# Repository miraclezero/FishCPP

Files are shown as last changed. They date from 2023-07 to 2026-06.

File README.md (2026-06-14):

# FishCPP

FishCPP is a Raspberry Pi-based system designed to conduct Conditioned Place Preference (CPP) experiments with zebrafish. The system automates camera recording, manages uniform arena illumination using NeoPixel LEDs, and uses RFID scans to initiate sessions and track device configurations.

## System Features

- **Arena Illumination**: Drives a 128-pixel WS2812B NeoPixel LED array to provide constant, uniform white light.
- **Physical Visual Cues**: Visual conditioning cues consist of physical, 3D-printed floor inserts placed within the arena: a black dots pattern and a grid pattern.
- **RFID-Initiated Sessions**: RFID scans are used to initiate the recording trials, advance experimental stages, and track system device IDs.
- **Automated Video Recording**: Controls the Raspberry Pi Camera Module to record trials (30 frames per second, 20-minute sessions) in raw `.h264` format.
- **Disk Space Verification**: Checks available disk space before starting a trial to ensure there is at least 2.5 GB of free storage.
- **Video Conversion Utility**: Includes a bash script ([convert_video.sh](file:///home/hao/Dropbox/git/FishCPP/convert_video.sh)) to convert raw `.h264` recordings to `.mp4` format using `ffmpeg`.

## Hardware Components

- Raspberry Pi (running Raspberry Pi OS)
- Raspberry Pi Camera Module
- WS2812B NeoPixel LED array (128 pixels, connected to GPIO pin 18)
- RFID Reader (operating in keyboard emulation mode)
- 3D-printed arena partition inserts (black dots versus grid pattern)

## Installation and Setup

1. Clone this repository to the Raspberry Pi:
   ```bash
   git clone https://github.com/miraclezero/FishCPP.git
   ```
2. Install the necessary Python packages:
   ```bash
   pip3 install rpi_ws281x adafruit-circuitpython-neopixel board requests
   ```
3. Enable the camera module using the Raspberry Pi configuration tool:
   ```bash
   sudo raspi-config
   ```
4. Verify that the configuration file `peerpub_config.json` exists in the `/home/pi/` directory. This file tracks the system device ID, current session ID, and experiment step.
5. Grant execute permissions to the video conversion utility:
   ```bash
   chmod +x convert_video.sh
   ```

## Experimental Workflow

1. **Initialization**: Start the main control program ([main.py](file:///home/hao/Dropbox/git/FishCPP/main.py)):
   ```bash
   python3 main.py
   ```
   The program checks for sufficient disk space (at least 2.5 GB free) and verifies that the directory is writable.
2. **Session Initiation**: Scan the appropriate RFID tag to register the subject configuration and initiate the recording script.
3. **Recording and Illumination**: The NeoPixel LED array lights up to provide constant white illumination. The system starts the camera to record a 20-minute trial, saving the video file to `/home/pi/video/`.
4. **Session Termination**: Scan the termination RFID tag to turn off the LEDs and conclude the session. The session counter in `peerpub_config.json` will automatically increment.
5. **Video Conversion**: Convert the raw video output to `.mp4` for analysis:
   ```bash
   ./convert_video.sh <filename_without_extension>
   ```

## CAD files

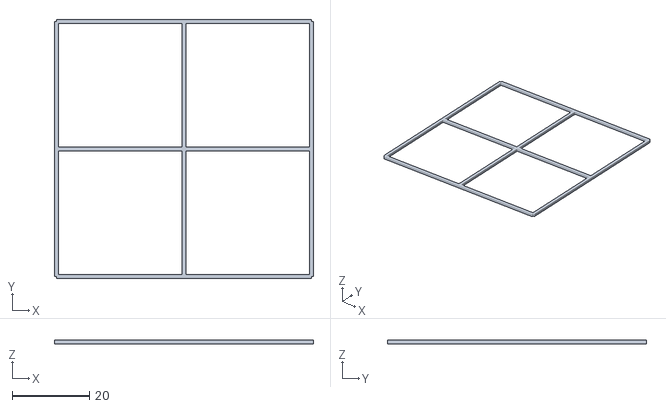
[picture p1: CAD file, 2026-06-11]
3D_design/fish_4_square_mark.stl
67.0 x 67.0 x 1.00

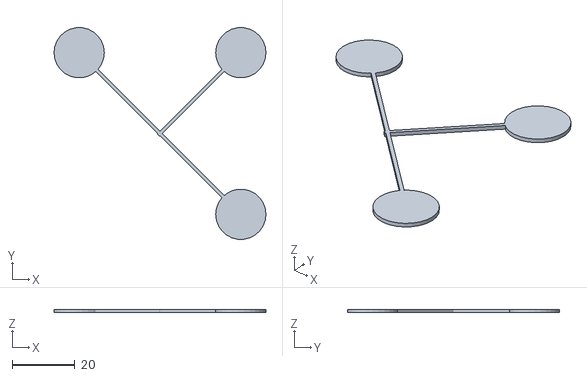
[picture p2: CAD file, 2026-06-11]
3D_design/fish_3dot_mark.stl
67.4 x 67.3 x 1.00

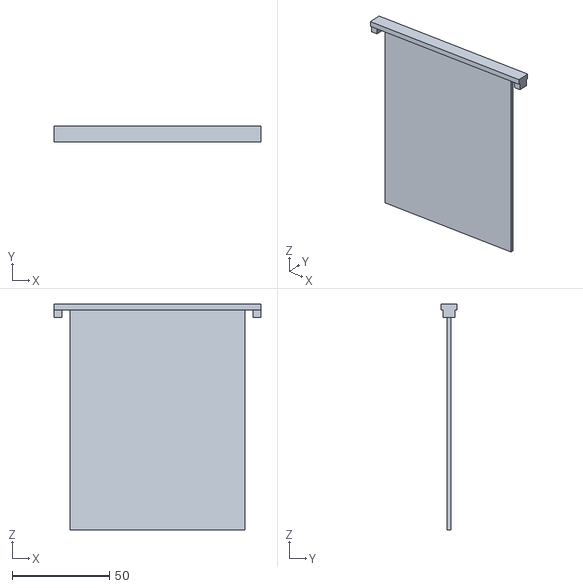
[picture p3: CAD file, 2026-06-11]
3D_design/fish_tank_mid.stl
106.0 x 8.00 x 116.0

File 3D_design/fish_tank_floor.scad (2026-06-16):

union(){
translate([15,15,0])rotate([0,0,45])cube([44, 1, 1], center=true);
translate([0,0,0])rotate([0,0,45])cube([1, 88, 1], center=true);
translate([25.7,25.7,0])rotate([0,0,0]) cylinder(r=8, h=1, center=true);
translate([-25.7,25.7,0])rotate([0,0,0]) cylinder(r=8, h=1, center=true);
translate([25.7,-25.7,0])rotate([0,0,0]) cylinder(r=8, h=1, center=true);
*translate([-25.7,-25.7,0])rotate([0,0,0]) cylinder(r=8, h=1, center=true);
}//3dot marker



union(){
    translate([0,0,0])cube([66, 1, 1], center=true);

    translate([0,33,0])cube([66, 1, 1], center=true);
    translate([0,-33,0])cube([66, 1, 1], center=true);
    translate([0,0,0])cube([1, 66, 1], center=true);

    translate([33,0,0])cube([1, 66, 1], center=true);
    translate([-33,0,0])cube([1, 66, 1], center=true);
} //grid marker

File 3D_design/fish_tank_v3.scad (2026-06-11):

$fn=50;
difference() {translate([0,0,0])cube([220+12+6, 87.5+10, 116.5+6+8+20], center=true);
 
    translate([0,-46,3+18])cube([220+5+6, 3, 116.5+8], center=true);
    translate([0,0,-50+10])cube ([220+5+8,87.5+10,4], center=true);

    translate([0,0,3]) cube ([220+6,87.5+11,116.5+8+20.1], center=true);
    translate([110,0,72])rotate([0,90,0]) cylinder(r=1.5, h=10);//inlet hole
    translate([-120,0,72])rotate([0,90,0]) cylinder(r=1.5, h=10);//inlet hole

}
difference(){translate([0,47.25,3+18-5])cube([220+14
, 3, 116.5], center=true);
    #translate([0,0,-50+10])cube ([230+5+6,84+11,3.5], center=true);
}
difference(){translate([0,0,-55])cube ([10,87.5+10,30], center=true);
    translate([0,0,-50+10])cube ([230+5+6,87.5+18,3.5], center=true);
}
translate([90,0,-73]) cube ([3,92+20,3], center=true);
translate([-90,0,-73]) cube ([3,92+20,3], center=true);
translate([30,0,-73]) cube ([3,92+20,3], center=true);
translate([-30,0,-73]) cube ([3,92+20,3], center=true);

//translate([0,-46,3+18])cube([220+6, 1, 117], center=true); //front cover board

//
//translate([0,0,0])cube([90, 2, 113], center=true);
//translate([0,2,58.])cube([105, 6, 3], center=true);
//#translate([51,2,56.])cube([4, 6, 7], center=true);
//#translate([-51,2,56.])cube([4, 6, 7], center=true); //division

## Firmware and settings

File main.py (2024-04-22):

#!/usr/bin/python3

import time
import subprocess
import board
import neopixel
import os
import sys
import shutil

from ids import IDS

os.system("clear")
## check available space on disk
free=shutil.disk_usage("/")[2]
freegb=free/(1024*1024*1024)
if (freegb<2.5):
    print ("The disk is full\n")
    print ("The disk is full\n")
    exit()
else:
    print (str(round(freegb,1)) +"Gb free")

## make sure drive is not write protected
try:
    with open('/home/pi/testdisk', 'w') as f:
        pass
except IOError as x:
    print (x.strerror)
    sys.exit("disk is not writable")

## collection session meta data
date = time.strftime("%Y-%m-%d", time.localtime())
d_time = time.strftime("_%H_%M_%S", time.localtime())
print ("current date_time:"+date+d_time)
ids = IDS()
devID=ids.devID
sesID=ids.sesID

pixels = neopixel.NeoPixel(board.D18, 128)
for i in range(128):
   pixels[i] = (15, 15, 15)

# collect info on color preference of the test subject
PrefID=input("Please scan the pattern/color preference of the fish, use yellow/blue if unknown\n")[-2:]
while PrefID != "ef" and PrefID != "62" and PrefID != "5d":
   print (PrefID)
   print("RFID is not correct, please scan either grid/yellow,  circle/blue, or  yellow/blue for unknown preference\n")
   PrefID = input("Please scan the pattern/color preference of the fish\n")[-2:]

if PrefID[-2:] == "ef": #0087b4ef
   Pref="Unknown"
if PrefID[-2:] == "62": #0084cb62
   #Pref="Blue"
   Pref="Circle"
if PrefID[-2:] == "5d": #002d2e5d
   #Pref = "Yellow"
   Pref="Grid"

# start camera 
os.system("raspivid --framerate 24 -t 600000 & ")


# which light to turn on?
TestID = input("please scan an RFID for the pattern/color of the LEDs\n")[-2:]
while TestID != "ef" and TestID != "62" and TestID != "5d": 
   print (TestID)
   print("RFID is not correct, please rescan")
   TestID = input("please scan an RFID for the pattern/color of the LEDs\n")[-2:]

os.system("killall raspivid")

if TestID[-2:] == "ef": #0087b4ef
   color="BI"
   #a,b,c,d,e,f = 15,11,0,0,0,18
   a,b,c,d,e,f = 15,15,15,15,15,15
	
if TestID[-2:] == "62": #0084cb62
   #color="BL"
   color="Circle"
   #a,b,c,d,e,f= 0,0,18,0,0,18
   a,b,c,d,e,f = 15,15,15,15,15,15
if TestID[-2:] == "5d": #002d2e5d
   #color = "YL"
   color="Grid"
   #a,b,c,d,e,f = 15,11,0,15,11,0
   a,b,c,d,e,f = 15,15,15,15,15,15

if Pref == "Unknown" and color !="BI":
   sys.exit("Fish with unknown pattern/color preference must be tested with both patterns/colors, please restart")

#pixels = neopixel.NeoPixel(board.D18, 128)
#for i in range(64):
#	pixels[i] = (a, b, c)
#for i in range(64,128):
#    pixels[i] = (d, e, f)

file_name= "/home/pi/video/CPP_" + devID + "-S" + str(sesID) + "-" + date + d_time + "-prefer-" + Pref +"-floor-" + color + ".h264"
print(file_name)
#msec=15*60*1000
msec=20*60*1000
os.system("raspivid --framerate 30 -hf -br 50 -pts " + file_name +".time.txt" + " -t "+ str(msec) + " -o " + file_name)
print("raspivid --framerate 30 -hf -br 50 -pts " + file_name +".time.txt" + " -t "+ str(msec) + " -o " + file_name)

ids.sessionIncrement()
time.sleep(1)

#stop if it is preference test, otherwise continue conditioning test
light=input('Please scan BI key to turn off light or other key to continue conditioning \n')[-2:]
if light[-2:] == "ef":
   for i in range(128):
      pixels = neopixel.NeoPixel(board.D18, 128)
      pixels[i] = (0, 0, 0)
      sys.exit("Preference test finished")


# collect info on color preference of the test subject
sesID=ids.sesID
PrefID=input("Please scan the pattern/color preference of the fish \n")[-2:]
while PrefID != "62" and PrefID != "5d":
   print (PrefID)
   print("RFID is not correct, please scan either grid/yellow or  circle/blue for conditioning. \n")
   PrefID = input("Please scan the pattern/color preference of the fish\n")[-2:]

if PrefID[-2:] == "62": #0084cb62
   #Pref="Blue"
   Pref="Circle"
if PrefID[-2:] == "5d": #002d2e5d
   #Pref = "Yellow"
   Pref="Grid"

# start camera 
os.system("raspivid --framerate 24 -t 600000 & ")

# which light to turn on?
TestID = input("please scan an RFID for the pattern/color of the LEDs\n")[-2:]
while TestID != "62" and TestID != "5d": 
   print (TestID)
   print("RFID is not correct, please rescan")
   TestID = input("please scan an RFID for the pattern/color of the LEDs\n")[-2:]

os.system("killall raspivid")

if TestID[-2:] == "62": #0084cb62
   #color="BL"
   color="Circle"
if TestID[-2:] == "5d": #002d2e5d
   #color = "YL"
   color="Grid"

file_name= "/home/pi/video/CPP_" + devID + "-S" + str(sesID) + "-" + date + d_time + "-prefer-" + Pref +"-floor-" + color + ".h264"
print(file_name)
#msec=15*60*1000
msec=20*60*1000
os.system("raspivid --framerate 30 -hf -br 50 -pts " + file_name +".time.txt" + " -t "+ str(msec) + " -o " + file_name)
print("raspivid --framerate 30 -hf -br 50 -pts " + file_name +".time.txt" + " -t "+ str(msec) + " -o " + file_name)

ids.sessionIncrement()
time.sleep(1)

light=input('Please scan any key to turn off light\n')[-2:]
time.sleep(1)
for i in range(128):
   pixels[i] = (0, 0, 0)
print("Conditioning finished")

#subprocess.call(['./convert_video.sh', str(file_name)])

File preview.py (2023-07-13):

#!/usr/bin/python

from picamera import PiCamera
import time
#import argparse

import board
import neopixel

#from ids import IDS


#date = time.strftime("%Y-%m-%d", time.localtime())
#d_time = time.strftime("_%H_%M_%S", time.localtime())

#ids = IDS()
#devID=ids.devID

#sesID=ids.sesID

#TestID = input("please scan a command RFID\n")[-8:]


camera = PiCamera()
camera.resolution = (1920, 800)
camera.framerate = 30
camera.brightness= 45
pixels = neopixel.NeoPixel(board.D18, 128)
for i in range(64):
	pixels[i] = (15, 6, 0)
for i in range(64,128):
        pixels[i] = (27, 0, 0)
camera.stop_preview()
camera.start_preview()
#file_name= "/home/pi/video/Soc_" + date + d_time + "_BOX_" + devID + "_S" + str(sesID) + "_" + color + ".h264"
#print(file_name)
#camera.start_recording(file_name)
time.sleep(120)
#camera.stop_recording()
camera.stop_preview()
for i in range(len(pixels)):
	pixels[i] = (0, 0, 0)

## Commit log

2026-06-11 add 3d files
    [fish_3dot_mark.stl, fish_4_square_mark.stl, fish_tank_mid.stl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]
2026-06-16 add floor marker file
    [fish_tank_floor.scad]
